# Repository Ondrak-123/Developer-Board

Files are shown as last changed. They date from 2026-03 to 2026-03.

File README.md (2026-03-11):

# RP2040 Developer Board
This project was great for learning something about the RP2040 ecosystem, great thing about this dev board is 16MB FLASH and 30 GPIOS.
You can use this developer board in breadboards, custom builds and any other way you can think of!

_**Featuring:**_
 
**MCU: Dual-core Arm Cortex-M0+ @ 133MHz.**

**Storage: 16MB (128Mbit) SPI Flash**

**Power: 3.3V LDO (MCP1700), up to 250mA.**

**Interface: USB-C 2.0 for programming and power.**

**Button for easy flashing.**

**This build features 0402 and QFLN parts so you will need some experience, steady hands, stencil and a solder paste/flux.**

**HOW TO FLASH:**
- This board supports the standard RP2040 bootloader
- Connect the board to your PC via USB-C
- Hold down the BOOTSEL button.
- The board will appear as a mass storage device
- Drag and drop your .uf2 file










**BOM:**



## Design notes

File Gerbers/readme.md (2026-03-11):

**Make sure to use the correct file when ordering JLCPCB/PCBWAY assembly service.**

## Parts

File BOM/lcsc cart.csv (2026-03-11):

Index | LCSC# | MPN | Manufacturer | Package | Customer # | Description | RoHS | Quantity | MOQ | Multiple | Unit Price($) | Extended Price($) | Product Link
1 | C315248 | CL05A106MP5NUNC | Samsung Electro-Mechanics | 0402 |  | 10uF ±20% 10V Ceramic Capacitor X5R 0402 | yes | 20 | 20 | 20 | 0.0091 | 0.18 | https://www.lcsc.com/product-detail/C315248.html
2 | C60474 | CC0402KRX7R7BB104 | YAGEO | 0402 |  | 100nF ±10% 16V Ceramic Capacitor X7R 0402 | yes | 100 | 100 | 100 | 0.0010 | 0.10 | https://www.lcsc.com/product-detail/C60474.html
3 | C2988369 | GT-USB-7010ASV | G-Switch | SMD |  | USB-C (USB TYPE-C) Receptacle Connector 16 Position Surface Mount, Right Angle | yes | 5 | 5 | 5 | 0.0803 | 0.40 | https://www.lcsc.com/product-detail/C2988369.html
4 | C5137486 | FCC0402N330J500AT | FOJAN | 0402 |  | 33pF ±5% 50V Ceramic Capacitor C0G 0402 | yes | 100 | 100 | 100 | 0.0009 | 0.09 | https://www.lcsc.com/product-detail/C5137486.html
5 | C107372 | CL05A105KQ5NNNC | Samsung Electro-Mechanics | 0402 |  | 1uF ±10% 6.3V Ceramic Capacitor X5R 0402 | yes | 100 | 100 | 100 | 0.0018 | 0.18 | https://www.lcsc.com/product-detail/C107372.html
6 | C42431804 | PH2.54-1X20P-H25 | JXTCONN | Through Hole,P=2.54mm |  | Pin Header 20 Position 2.54mm Pitch Single Row Through Hole -40℃~+105℃ | yes | 5 | 5 | 5 | 0.0920 | 0.46 | https://www.lcsc.com/product-detail/C42431804.html
7 | C32713269 | HX PZ2.54-1x3P ZZ | hanxia | Through Hole,P=2.54mm |  | Pin Header 3 Position 2.54mm Pitch Single Row Through Hole -40℃~+105℃ | yes | 5 | 5 | 5 | 0.0200 | 0.10 | https://www.lcsc.com/product-detail/C32713269.html
8 | C2906948 | FRC0402J512 TS | FOJAN | 0402 |  | 5.1kΩ ±5% 62.5mW 0402 Thick Film Resistor | yes | 100 | 100 | 100 | 0.0005 | 0.05 | https://www.lcsc.com/product-detail/C2906948.html
9 | C2906864 | FRC0402F1001TS | FOJAN | 0402 |  | 1kΩ ±1% 62.5mW 0402 Thick Film Resistor | yes | 100 | 100 | 100 | 0.0006 | 0.06 | https://www.lcsc.com/product-detail/C2906864.html
10 | C138021 | RC0402FR-0727RL | YAGEO | 0402 |  | 27Ω ±1% 62.5mW 0402 Thick Film Resistor | yes | 100 | 100 | 100 | 0.0008 | 0.08 | https://www.lcsc.com/product-detail/C138021.html
11 | C2906861 | FRC0402F1002TS | FOJAN | 0402 |  | 10kΩ ±1% 62.5mW 0402 Thick Film Resistor | yes | 100 | 100 | 100 | 0.0006 | 0.06 | https://www.lcsc.com/product-detail/C2906861.html
12 | C36498960 | HX 3x6x2.5A-2.5N | hanxia | SMD,6x3mm |  | Tactile Switch SPST 250gf 2.5mm SMD (SMT) Tab 6mm x 3.6mm Surface Mount | yes | 5 | 5 | 5 | 0.0190 | 0.10 | https://www.lcsc.com/product-detail/C36498960.html
13 | C41381676 | HMCP1700T-3302E/TT | HXY MOSFET | SOT-23 |  | 3.3V 6V Positive Fixed SOT-23 Voltage Regulators - Linear, Low Drop Out (LDO) Regulators RoHS | yes | 5 | 5 | 5 | 0.1062 | 0.53 | https://www.lcsc.com/product-detail/C41381676.html
14 | C113767 | W25Q128JVSIQ | Winbond | SOIC-8-208mil |  | 2.7V~3.6V 128Mbit 133MHz SPI SOIC-8-208mil Memory (ICs) RoHS | yes | 1 | 1 | 1 | 2.4116 | 2.41 | https://www.lcsc.com/product-detail/C113767.html
15 | C5280576 | XL2EL89CSI-111YLC-12M | YXC Crystal Oscillators | SMD3225-4P |  | Crystal 12MHz ±10ppm 20pF SMD3225-4P | yes | 10 | 10 | 10 | 0.0620 | 0.62 | https://www.lcsc.com/product-detail/C5280576.html
16 | C2040 | RP2040 | Raspberry Pi | LQFN-56(7x7) |  | 133MHz 30 LQFN-56(7x7) Microcontrollers RoHS | yes | 1 | 1 | 1 | 0.9482 | 0.95 | https://www.lcsc.com/product-detail/C2040.html

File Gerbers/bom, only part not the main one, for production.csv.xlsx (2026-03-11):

Designator,LCSC Part,Quantity,Value,Footprint
C1, C2,C15525,2,10uF,0402
C10, C11, C12, C13, C17, C4, C5, C6, C7, C8, C9,C1525,11,0.1uF,0402
C14, C3,C52923,2,1uF,0402
C15, C16,C32162,2,33pF,0402
J1,C719112,1,USB-C 2.0 (16P),USB-C-16P
J2, J3,C124356,2,Conn_01x20,2.54mm-1x20
J4,C2818960,1,Conn_01x03,2.54mm-1x03
R1, R2,C25905,2,5.1k,0402
R3, R5,C25076,2,1k,0402
R4,C25744,1,10k,0402
R6, R7,C25102,2,27R,0402
SW1,C6230,1,Tactile Switch,3x6mm SMD
U1,C517721,1,MCP1700T-3302E/TT,SOT-23
U2,C2040,1,RP2040,QFN-56
U3,C82490,1,W25Q128JVSIQ,SOIC-8
Y1,C90039,1,12MHz Crystal,3225-4P

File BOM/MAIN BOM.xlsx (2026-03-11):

Designator | LCSC Part | Quantity | Value | Footprint | LCSC Link | Price per piece: | MOQ: | Price total:
C1, C2 | C315248 | 2 | 10uF | 0402 | https://www,lcsc,com/product-detail/C315248,html?s_z=n_10uF%25200402 (https://www.lcsc.com/product-detail/C315248.html?s_z=n_10uF%25200402) | 0.0091 | 20 | $0.18
C4, C5, C6, C7, C8, C9, C10, C11, C12, C13, C17 | C60474 | 11 | 0,1uF | 0402 | https://www,lcsc,com/product-detail/C60474,html?s_z=n_100nF%25200402%25C2%25A8 (https://www.lcsc.com/product-detail/C60474.html?s_z=n_100nF%25200402%25C2%25A8) | 0.0010 | 100 | $0.10 | MOQ stands for Minimal Order Quantity, this is very important, if I want to order 5 pieces but the MOQ is 10 pieces I need to order 10 pieces, Everytime the MOQ is higher than the quantity needed, is the best price for these components even with the included components or there is not any other better/cheaper way,
C3, C14 | C107372 | 2 | 1uF | 0402 | https://www,lcsc,com/product-detail/C107372,html?s_z=n_1uF%25200402 (https://www.lcsc.com/product-detail/C107372.html?s_z=n_1uF%25200402) | 0.0018 | 100 | $0.18
C15, C16 | C5137486 | 2 | 33pF | 0402 | https://www,lcsc,com/product-detail/C5137486,html?s_z=n_33pF%25200402 (https://www.lcsc.com/product-detail/C5137486.html?s_z=n_33pF%25200402) | 0.0009 | 100 | $0.09
J1 | C2988369 | 1 | USB-C 2,0 | USB-C-16P | https://www,lcsc,com/product-detail/C2988369,html?s_z=n_USB-C%25C2%25A8 (https://www.lcsc.com/product-detail/C2988369.html?s_z=n_USB-C%25C2%25A8) | 0.0803 | 5 | $0.40
J2, J3 | C42431804 | 2 | Conn_01x20 | 2,54mm-1x20 |  | 0.0920 | 5 | $0.46
J4 | C32713269 | 1 | Conn_01x03 | 2,54mm-1x03 | https://www,lcsc,com/product-detail/C32713269,html?s_z=n_conn%25201%2a03 (https://www.lcsc.com/product-detail/C32713269.html?s_z=n_conn%25201%2a03) | 0.0200 | 5 | $0.10
R1, R2 | C2906948 | 2 | 5,1k | 0402 | https://www,lcsc,com/product-detail/C2906948,html?s_z=n_5,1k%25200402 (https://www.lcsc.com/product-detail/C2906948.html?s_z=n_5.1k%25200402) | 0.0005 | 100 | $0.05
R3, R5 | C2906864 | 2 | 1k | 0402 | https://www,lcsc,com/product-detail/C2906864,html?s_z=n_1k%25200402 (https://www.lcsc.com/product-detail/C2906864.html?s_z=n_1k%25200402) | 0.0006 | 100 | $0.06
R4 | C2906861 | 1 | 10k | 0402 | https://www,lcsc,com/product-detail/C2906861,html?s_z=n_10k%25200402 (https://www.lcsc.com/product-detail/C2906861.html?s_z=n_10k%25200402) | 0.0006 | 100 | $0.06
R6, R7 | C138021 | 2 | 27R | 0402 | https://www,lcsc,com/product-detail/C138021,html?s_z=n_27r%25200402 (https://www.lcsc.com/product-detail/C138021.html?s_z=n_27r%25200402) | 0.0008 | 100 | $0.08
SW1 | C36498960 | 1 | SW_Push | SMD-3x6 | https://www,lcsc,com/product-detail/C36498960,html?s_z=n_SMD%25203x6%2520sw (https://www.lcsc.com/product-detail/C36498960.html?s_z=n_SMD%25203x6%2520sw) | 0.0200 | 5 | $0.10 | All prices are in USD,
U1 | C41381676 | 1 | MCP1700-3,3 | SOT-23 | https://www,lcsc,com/product-detail/C41381676,html?s_z=n_MCP1700%25203,3v%2520sot23 (https://www.lcsc.com/product-detail/C41381676.html?s_z=n_MCP1700%25203.3v%2520sot23) | 0.1062 | 5 | $0.53
U2 | C2040 | 1 | RP2040 | QFN-56 | https://www,lcsc,com/product-detail/C2040,html?s_z=n_RP2040 (https://www.lcsc.com/product-detail/C2040.html?s_z=n_RP2040) | 0.9482 | 1 | $0.95 | The LCSC cart is downloadable in the BOM directory.
U3 | C113767 | 1 | W25Q128 | SOIC-8 | https://www,lcsc,com/product-detail/C113767,html?s_z=n_W25Q128 (https://www.lcsc.com/product-detail/C113767.html?s_z=n_W25Q128) | 2.4116 | 1 | $2.41
Y1 | C5280576 | 1 | 12MHz | 3225-4P | https://www,lcsc,com/product-detail/C5280576,html?s_z=n_12MhZ%2520crystal%2520 (https://www.lcsc.com/product-detail/C5280576.html?s_z=n_12MhZ%2520crystal%2520) | 0.0620 | 10 | $0.62
LCSC Shipping | - | 1 | - | - | - | - | - | $9.24
LCSC Handling Fee | - | 1 | - | - | - | - | - | $3.00
JLCPCB PCB + Edge Deburring (2$ + 0,1$) | - | 1 | - | - | - | - | - | $2.10
JLCPCB Stencil | - | 1 | - | - | - | - | - | $3.05
JLCPCB Shipping | - | 1 | - | - | - | - | - | $9.33
JLCPCB Customs & Taxes | - | 1 | - | - | - | - | - | $3.05
Grand total: |  |  |  |  |  |  |  | $36.14

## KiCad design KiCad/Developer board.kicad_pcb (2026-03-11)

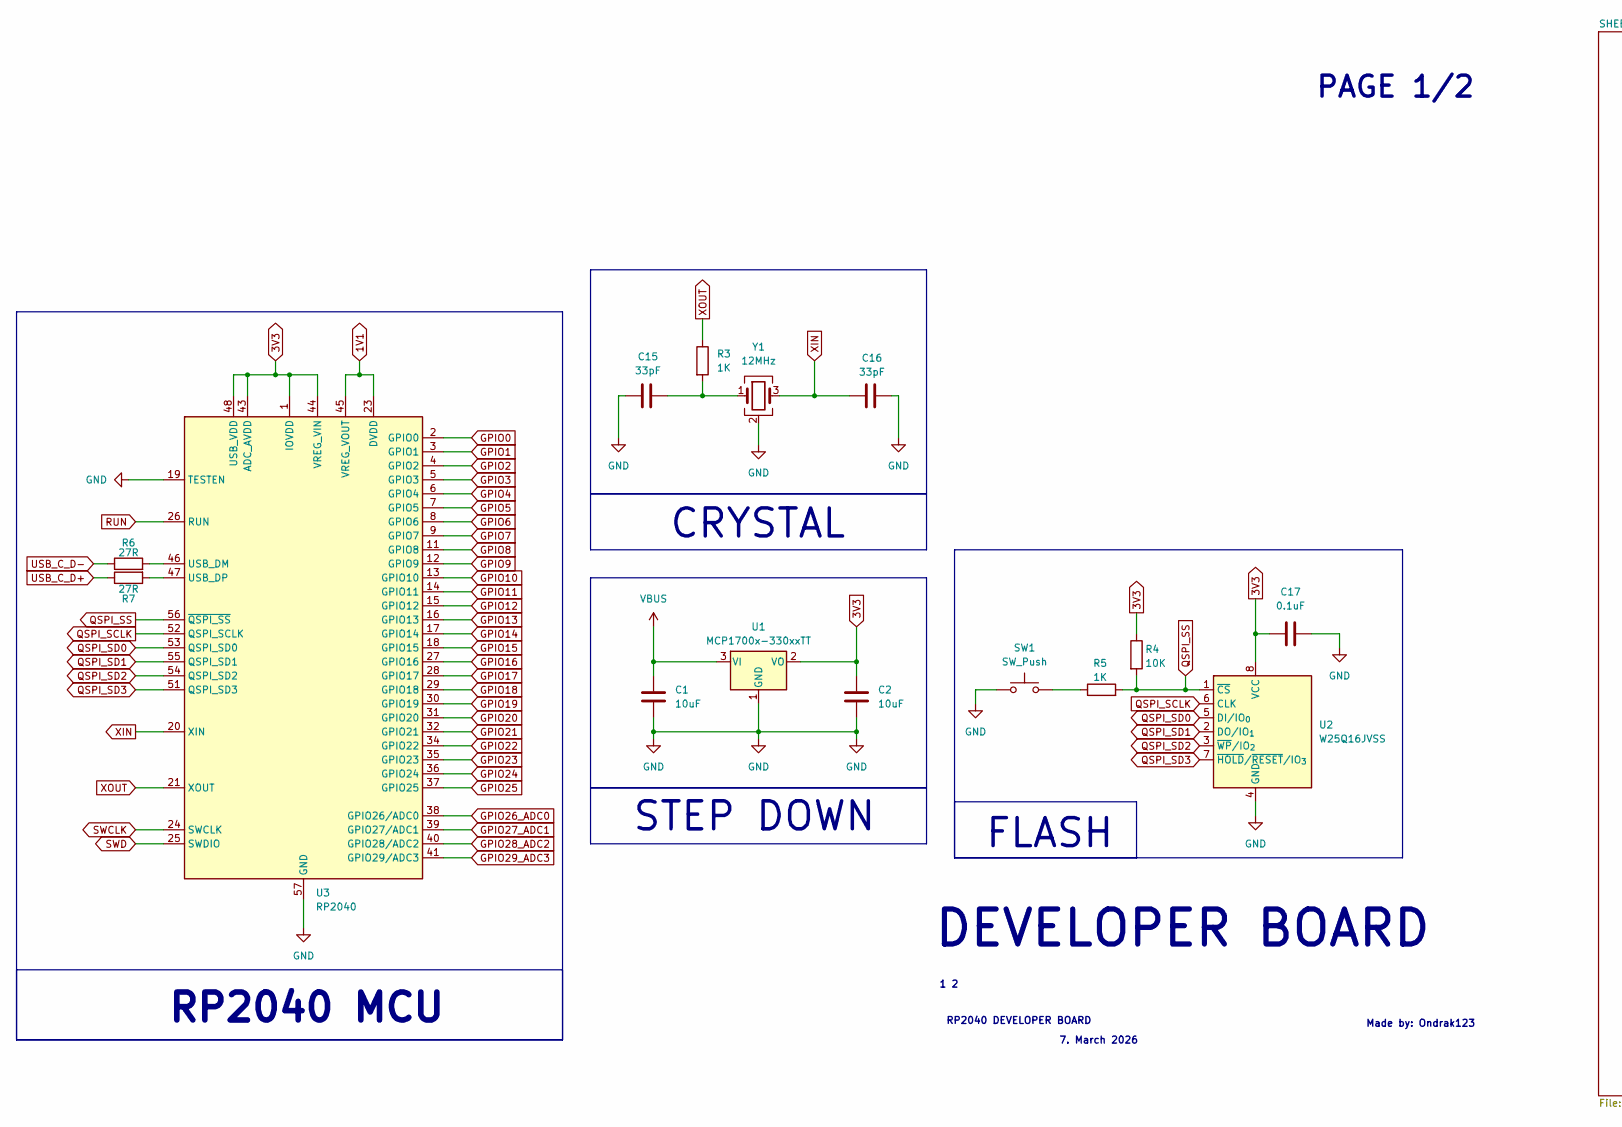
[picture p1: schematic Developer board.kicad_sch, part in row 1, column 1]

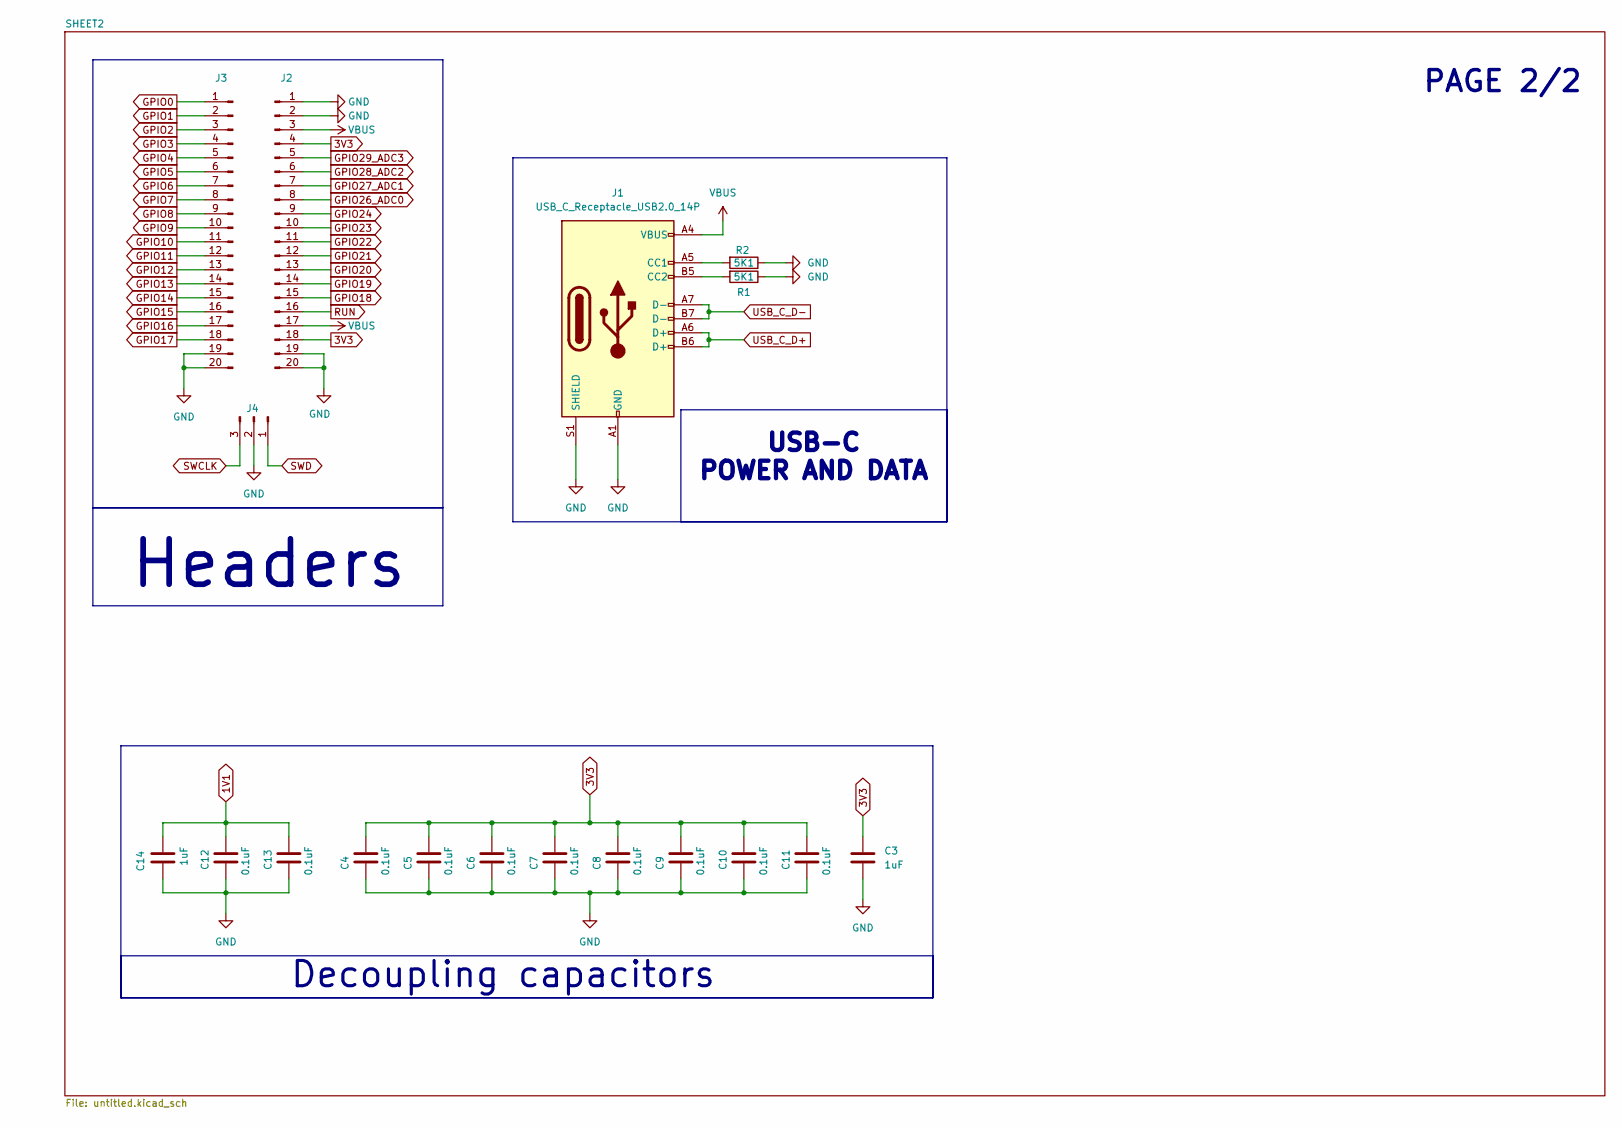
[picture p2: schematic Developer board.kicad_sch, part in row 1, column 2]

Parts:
C1, C2: 10uF; C_0603_1608Metric
C3, C14: 1uF; C_0603_1608Metric
C4, C5, C6, C7, C8, C9, C10, C11, C12, C13, C17: 0.1uF; C_0402_1005Metric_Pad0.74x0.62mm_HandSolder
C15, C16: 33pF; C_0402_1005Metric_Pad0.74x0.62mm_HandSolder
J1: USB_C_Receptacle_USB2.0_14P; USB_C_Receptacle_GCT_USB4105-xx-A_16P_TopMnt_Horizontal
J2, J3: Conn_01x20_Pin; PinHeader_1x20_P2.54mm_Vertical
J4: Conn_01x03_Pin; PinHeader_1x03_P2.54mm_Vertical
R1, R2: 5K1; R_0402_1005Metric_Pad0.72x0.64mm_HandSolder
R3, R5: 1K; R_0402_1005Metric_Pad0.72x0.64mm_HandSolder
R4: 10K; R_0402_1005Metric_Pad0.72x0.64mm_HandSolder
R6, R7: 27R; R_0402_1005Metric_Pad0.72x0.64mm_HandSolder
SW1: SW_Push; SW_Push_SPST_NO_Alps_SKRK
U1: MCP1700x-330xxTT; SOT-23
U2: W25Q16JVSS; SOIC-8_5.3x5.3mm_P1.27mm
U3: RP2040; QFN-56-1EP_7x7mm_P0.4mm_EP3.2x3.2mm
Y1: 12MHz; Crystal_SMD_3225-4Pin_3.2x2.5mm_HandSoldering

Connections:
1V1: C12.1, C13.1, C14.1, U3.23 (DVDD), U3.45 (VREG_VOUT), U3.50 (DVDD)
3V3: C2.1, C3.1, C4.1, C5.1, C6.1, C7.1, C8.1, C9.1, C10.1, C11.1, C17.1, J2.4, J2.18, R4.1, U1.2 (VO), U2.8 (VCC), U3.1 (IOVDD), U3.10 (IOVDD), U3.22 (IOVDD), U3.33 (IOVDD), U3.42 (IOVDD), U3.43 (ADC_AVDD), U3.44 (VREG_VIN), U3.48 (USB_VDD), U3.49 (IOVDD)
GND: C1.2, C2.2, C3.2, C4.2, C5.2, C6.2, C7.2, C8.2, C9.2, C10.2, C11.2, C12.2, C13.2, C14.2, C15.1, C16.1, C17.2, J1.A1 (GND), J1.A12 (GND), J1.B1 (GND), J1.B12 (GND), J1.S1 (SHIELD), J2.1, J2.2, J2.19, J2.20, J3.19, J3.20, J4.2, R1.1, R2.1, SW1.1, U1.1 (GND), U2.4 (GND), U3.19 (TESTEN), U3.57 (GND), Y1.2 (G), Y1.4 (G)
GPIO0: J3.1, U3.2 (GPIO0)
GPIO1: J3.2, U3.3 (GPIO1)
GPIO2: J3.3, U3.4 (GPIO2)
GPIO3: J3.4, U3.5 (GPIO3)
GPIO4: J3.5, U3.6 (GPIO4)
GPIO5: J3.6, U3.7 (GPIO5)
GPIO6: J3.7, U3.8 (GPIO6)
GPIO7: J3.8, U3.9 (GPIO7)
GPIO8: J3.9, U3.11 (GPIO8)
GPIO9: J3.10, U3.12 (GPIO9)
GPIO10: J3.11, U3.13 (GPIO10)
GPIO11: J3.12, U3.14 (GPIO11)
GPIO12: J3.13, U3.15 (GPIO12)
GPIO13: J3.14, U3.16 (GPIO13)
GPIO14: J3.15, U3.17 (GPIO14)
GPIO15: J3.16, U3.18 (GPIO15)
GPIO16: J3.17, U3.27 (GPIO16)
GPIO17: J3.18, U3.28 (GPIO17)
GPIO18: J2.15, U3.29 (GPIO18)
GPIO19: J2.14, U3.30 (GPIO19)
GPIO20: J2.13, U3.31 (GPIO20)
GPIO21: J2.12, U3.32 (GPIO21)
GPIO22: J2.11, U3.34 (GPIO22)
GPIO23: J2.10, U3.35 (GPIO23)
GPIO24: J2.9, U3.36 (GPIO24)
GPIO25: U3.37 (GPIO25)
GPIO26_ADC0: J2.8, U3.38 (GPIO26/ADC0)
GPIO27_ADC1: J2.7, U3.39 (GPIO27/ADC1)
GPIO28_ADC2: J2.6, U3.40 (GPIO28/ADC2)
GPIO29_ADC3: J2.5, U3.41 (GPIO29/ADC3)
unnamed: C15.2, R3.2, Y1.1
unnamed: J1.A5 (CC1), R2.2
unnamed: J1.B5 (CC2), R1.2
unnamed: R5.1, SW1.2
unnamed: R6.2, U3.46 (USB_DM)
unnamed: R7.2, U3.47 (USB_DP)
QSPI_SCLK: U2.6 (CLK), U3.52 (QSPI_SCLK)
QSPI_SD0: U2.5 (DI/IO_{0}), U3.53 (QSPI_SD0)
QSPI_SD1: U2.2 (DO/IO_{1}), U3.55 (QSPI_SD1)
QSPI_SD2: U2.3 (~WP/IO_{2}), U3.54 (QSPI_SD2)
QSPI_SD3: U2.7 (~HOLD/~RESET/IO_{3}), U3.51 (QSPI_SD3)
QSPI_SS: R4.2, R5.2, U2.1 (~CS), U3.56 (~QSPI_SS)
RUN: J2.16, U3.26 (RUN)
SWCLK: J4.3, U3.24 (SWCLK)
SWD: J4.1, U3.25 (SWDIO)
USB_C_D+: J1.A6 (D+), J1.B6 (D+), R7.1
USB_C_D-: J1.A7 (D-), J1.B7 (D-), R6.1
VBUS: C1.1, J1.A4 (VBUS), J1.A9 (VBUS), J1.B4 (VBUS), J1.B9 (VBUS), J2.3, J2.17, U1.3 (VI)
XIN: C16.2, U3.20 (XIN), Y1.3
XOUT: R3.1, U3.21 (XOUT)

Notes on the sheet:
STEP DOWN
Made by: Ondrak123
PAGE 2/2
1 2
RP2040 MCU
PAGE 1/2
CRYSTAL
DEVELOPER BOARD
FLASH
Headers
7. March 2026
Decoupling capacitors
USB-C POWER AND DATA
RP2040 DEVELOPER BOARD

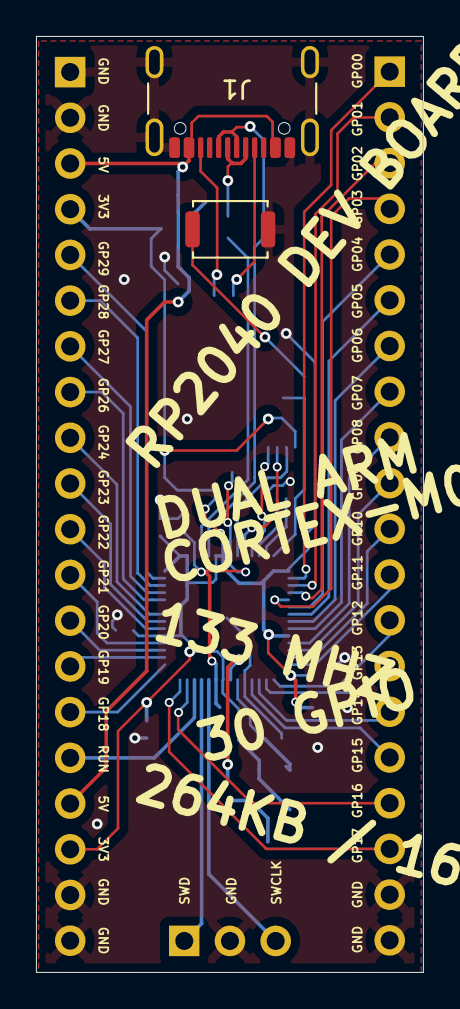
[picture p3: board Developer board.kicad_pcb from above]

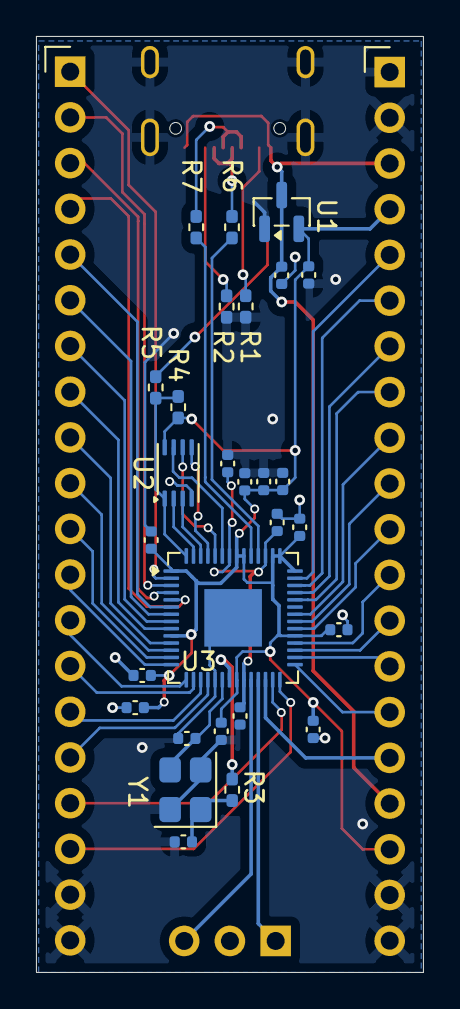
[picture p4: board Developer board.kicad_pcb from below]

Board: 2 copper layers, 21.5 x 52.0 mm, 33 parts (30 on the bottom side), 52 nets.

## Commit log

2026-03-11 Update assembly service instructions in readme
2026-03-11 Update README with RP2040 board details
    Added detailed specifications and flashing instructions for the RP2040 Developer Board.
2026-03-11 gerbers update
2026-03-11 graphics update
    [Developer board.kicad_pcb]
